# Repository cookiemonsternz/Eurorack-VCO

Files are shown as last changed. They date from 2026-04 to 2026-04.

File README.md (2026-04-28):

# VCO
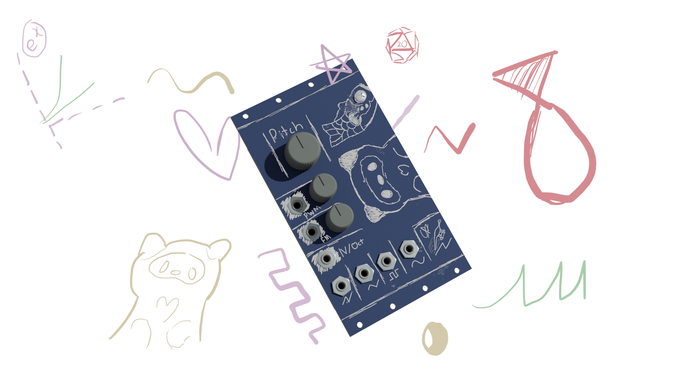
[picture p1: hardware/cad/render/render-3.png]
Render 3

_DIY VCO Eurorack module with saw, triangle, square, and sine output._

#### What?
This is a minimal, hand soldered, sawtooth core VCO module I designed to be inexpensive, fully analog, and with a variety of outputs. To that end, the module features sawtooth, triangle, pwm, and sine outputs, with pwm, fm, and pitch inputs. It internally features temparature tolerant circuitry, as well as having coarse and fine tuning, as well as pitch scale.

#### Why?
DIY eurorack modules are not particularly uncommon, but they often come at the cost of features. A lot of the time such modules lack functionality common to other prebuilt designs, and I wanted to change this. This module has a full standard feature set, including proper PWM and sine outputs.

Also, a lot of eurorack modules are quite bland in terms of design, often lacking any personality and focusing purely on cramming as many knobs in as possible. Here I've taken time to add some (imo) nice art and some extra space on the module.

#### How to use?
This should be pretty self explanatory:
- The pitch knob controls the pitch of the module. If using CV pitch, be sure to set this to the minimum.
- PWM input adjusts the width of the PWM output. The knob to the right of it controls the scale of the PWM CV.
- FM input modulates the frequency by the CV input. The knob controls the FM scale.
- Outputs are along the bottom!
Sawtooth, Triangle, PWM, and Sine, in that order.

#### Tuning
Hopefully, once you've received your pcb and soldered it up, it should look something like this:
Board back

Before you properly use it, you'll likely want to tune it.
This can be done by following these instructions:

1. Turn the `pitch` knob on the front of the board to the minimum.
2. Adjust the `coarse` trimpot on the back until the output is roughly A0 (~27.5Hz)
3. Adjust the `fine` trimpot to accurately tune the output.
4. Send 5V into the `1V/OCT` input on the front of the board.
5. Adjust the `scale` trimpot until your output is roughly A4 (~440Hz)
6. Repeat steps 2-5 several times until tuning is accurate at both A0 and A4.

Should the PWM output sound weird, just muck around with the `pwm` trimpot until it sounds normal.
Same thing with the sine or triangle output, just adjust the `tri off` trimpot.

#### Simulations
I've included the simulations I created on LTSpice; VCO contains the full circuit, PWM just the pwm section.

## Renders
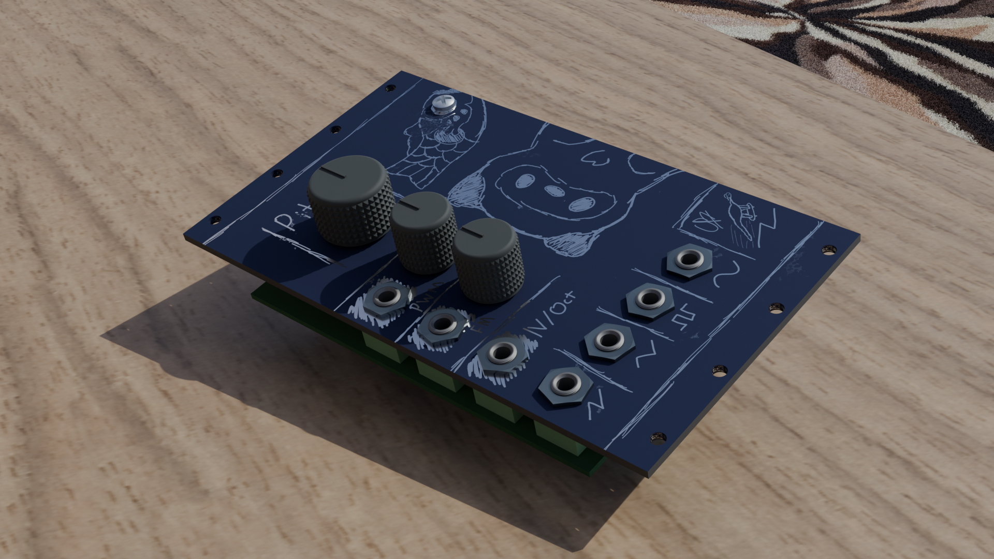
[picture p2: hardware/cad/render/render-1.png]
Render 1

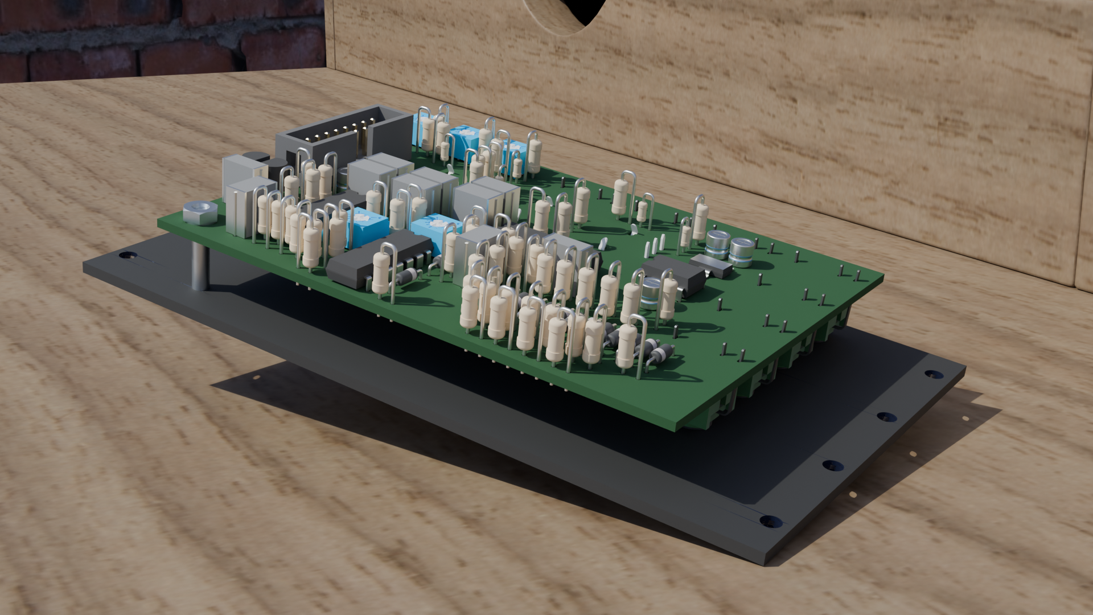
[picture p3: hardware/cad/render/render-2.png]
Render 2

Board Front
Board Back

## Zine Page

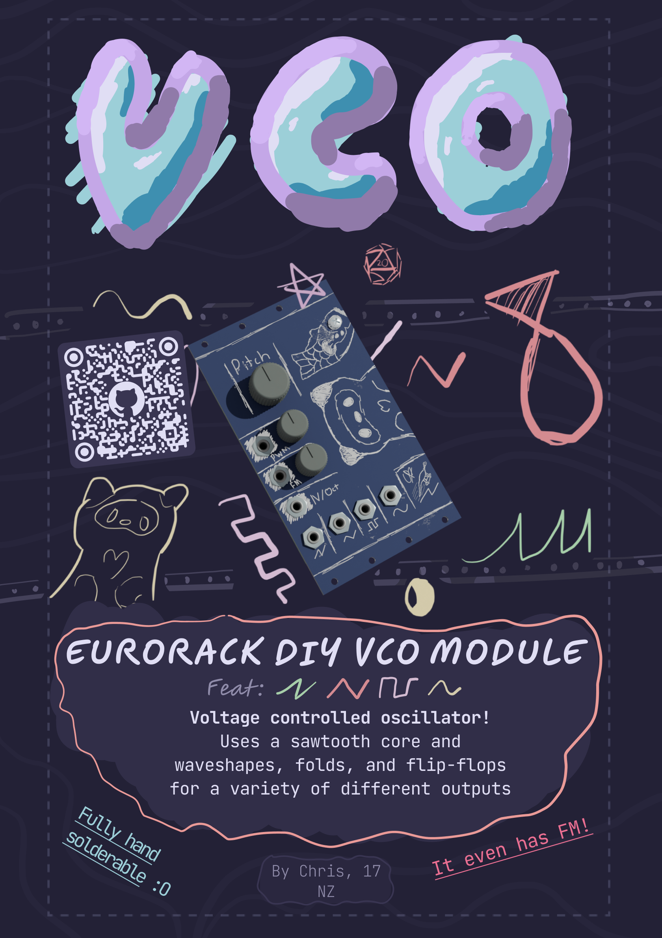
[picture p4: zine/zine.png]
Zine page


## BOM
_Needed is how many I personally need :)_
| Part | Quantity | Needed | Source | Link | Lot / Min Amount | Unit  | Net | Running | Total Incl. Unneeded |
|---|---|---|---|---|---|---|---|---|---|
| 10n Capacitor | 2 | 0 | LCSC | https://www.lcsc.com/product-detail/C20415578.html | 10 | $0.59 | NA | $0.00 | $0.59 |
| 100n Capacitor | 7 | 0 | LCSC | https://www.lcsc.com/product-detail/C49002969.html | 10 | $0.41 | NA | $0.00 | $1.00 |
| 10u Capacitor | 4 | 0 | LCSC | https://www.lcsc.com/product-detail/C49002971.html | 5 | $0.81 | NA | $0.00 | $1.81 |
| 22u Capacitor | 1 | 0 | LCSC | https://www.lcsc.com/product-detail/C18214342.html | 20 | $0.85 | NA | $0.00 | $2.66 |
| 100k Resistor | 15 | 0 | LCSC | https://www.lcsc.com/product-detail/C2843019.html | 100 | $0.82 | NA | $0.00 | $3.48 |
| 10k Resistor | 7 | 0 | LCSC | https://www.lcsc.com/product-detail/C2903232.html | 100 | $0.68 | NA | $0.00 | $4.16 |
| 1k Resistor | 6 | 0 | LCSC | https://www.lcsc.com/product-detail/C2903245.html | 100 | $0.68 | NA | $0.00 | $4.84 |
| 1M Resistor | 2 | 0 | LCSC | https://www.lcsc.com/product-detail/C2903250.html | 100 | $0.79 | NA | $0.00 | $5.63 |
| 47k Resistor | 3 | 0 | LCSC | https://www.lcsc.com/product-detail/C1364438.html | 100 | $0.52 | NA | $0.00 | $6.15 |
| 68k Resistor | 1 | 0 | LCSC | https://www.lcsc.com/product-detail/C1364508.html | 100 | $0.55 | NA | $0.00 | $6.70 |
| 14k Resistor | 1 | 0 | LCSC | https://www.lcsc.com/product-detail/C1369251.html | 100 | $0.87 | NA | $0.00 | $7.57 |
| 20k Resistor | 1 | 0 | LCSC | https://www.lcsc.com/product-detail/C119353.html | 50 | $0.57 | NA | $0.00 | $8.14 |
| 200r Resistor | 1 | 0 | LCSC | https://www.lcsc.com/product-detail/C714576.html | 20 | $0.68 | NA | $0.00 | $8.82 |
| 2k Resistor | 1 | 0 | LCSC | https://www.lcsc.com/product-detail/C119330.html | 50 | $0.52 | NA | $0.00 | $9.34 |
| 100r Resistor | 2 | 0 | LCSC | https://www.lcsc.com/product-detail/C1366145.html | 10 | $0.57 | NA | $0.00 | $9.91 |
| 33r Resistor | 2 | 0 | LCSC | https://www.lcsc.com/product-detail/C713968.html | 100 | $0.70 | NA | $0.00 | $10.61 |
| 82r Resistor | 2 | 0 | LCSC | https://www.lcsc.com/product-detail/C119302.html | 50 | $0.50 | NA | $0.00 | $11.11 |
| 470r Resistor | 1 | 0 | LCSC | https://www.lcsc.com/product-detail/C129899.html | 50 | $0.54 | NA | $0.00 | $11.65 |
| 47r Resistor | 2 | 0 | LCSC | https://www.lcsc.com/product-detail/C119296.html | 50 | $0.57 | NA | $0.00 | $12.22 |
| 330r Resistor | 1 | 0 | LCSC | https://www.lcsc.com/product-detail/C713986.html | 100 | $0.75 | NA | $0.00 | $12.97 |
| 30r Resistor | 2 | 0 | LCSC | https://www.lcsc.com/product-detail/C18724276.html | 50 | $0.51 | NA | $0.00 | $13.48 |
| 120r Resistor | 1 | 0 | LCSC | https://www.lcsc.com/product-detail/C173141.html | 50 | $1.10 | NA | $0.00 | $14.58 |
| 39r Resistor | 2 | 0 | LCSC | https://www.lcsc.com/product-detail/C119294.html | 50 | $0.53 | NA | $0.00 | $15.11 |
| 6.8k Resistor | 1 | 0 | LCSC | https://www.lcsc.com/product-detail/C3397534.html | 50 | $0.80 | NA | $0.00 | $15.91 |
| BC557B | 1 | 0 | LCSC | https://www.lcsc.com/product-detail/C512874.html | 5 | $0.43 | NA | $0.00 | $16.34 |
| BC547B | 1 | 0 | LCSC | https://www.lcsc.com/product-detail/C900798.html | 5 | $0.42 | NA | $0.00 | $16.76 |
| Diode (1N4148) | 15 | 15 | LCSC | https://www.lcsc.com/product-detail/C402212.html | 50 | $0.47 | $0.47 | $0.47 | $17.23 |
| 3362P 1k Trimpot | 1 | 1 | LCSC | https://www.lcsc.com/product-detail/C118947.html | 5 | $0.72 | $0.72 | $1.19 | $17.95 |
| 3362P 10k Trimpot | 1 | 1 | LCSC | https://www.lcsc.com/product-detail/C118956.html | 5 | $0.82 | $0.82 | $2.01 | $18.77 |
| 3362P 100k Trimpot | 3 | 3 | LCSC | https://www.lcsc.com/product-detail/C118966.html | 5 | $0.77 | $0.77 | $2.78 | $19.54 |
| RK097 1M Vertical Pot | 1 | 0 | Aliexpress | https://www.aliexpress.com/item/1005007278123055.html | 5 | $1.83 | NA | $2.78 | $21.37 |
| RK097 100k Vertical Pot | 2 | 0 | Aliexpress | https://www.aliexpress.com/item/1005007278123055.html | 5 | $1.83 | NA | $2.78 | $23.20 |
| 10k NTC Thermistor | 5 | 5 | LCSC | https://www.lcsc.com/product-detail/C13879.html | 10 | $0.44 | $0.44 | $3.22 | $23.64 |
| TL074 | 3 | 3 | LCSC | https://www.lcsc.com/product-detail/C133542.html | 1 | $0.69 | $2.08 | $5.30 | $24.33 |
| AMS1117-2.5 SOT223 | 1 | 1 | LCSC | https://www.lcsc.com/product-detail/C12087.html | 5 | $0.26 | $1.29 | $6.59 | $24.59 |
| TC7660 | 1 | 1 | LCSC | https://www.lcsc.com/product-detail/C640848.html | 1 | $1.90 | $1.90 | $8.49 | $26.49 |
| PJ301F Audio Jack | 7 | 7 | Aliexpress | https://www.aliexpress.com/item/1005007344185064.html | 10 | $3.66 | $3.66 | $12.15  | $30.15 |
| 2x8 2.54mm IDC | 1 | 1 | LCSC | https://www.lcsc.com/product-detail/C7430313.html | 5 | $0.08 | $0.42 | $12.57  | $30.23 |
| Aluminium Plate (100x200x2mm) | 1 | 1 | Aliexpress | www.aliexpress.com/item/1005007160296738.html | 1 | $6.23 | $6.23 | $18.80  | $36.46 |
| M3x18mm Bolt | 1 | 0 | Aliexpress | https://www.aliexpress.com/item/32810852732.html | 50 | $6.43 | NA | $18.80  | $42.89 |
| M3 Hex Nut | 1 | 0 | Aliexpress | https://www.aliexpress.com/item/1005007593861199.html | 50 | $4.89 | NA | $18.80  | $47.78 |

| Totals | Cost |
|---|---|
| Aliexpress, Inc. Shipping + Tax | $12.67 |
| LCSC, Inc. Shipping + Tax | $11.83 |
| Totals | $24.50 |

## CAD Links
Heres the links to the CAD source, Onshape:
[Panel source](https://cad.onshape.com/documents/2eb193865095ed64e7d8f18f/w/39a8bf3aab3e330703d68c10/e/c0b4bed9abee9891cf892ccc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)

## Directory Structure
- **hardware/**
    - **bom/** - BOM Files (CSV and LibreOffice Calc)
    - **cad/** - CAD Files
        - **render/** - Files for rendering (inc. gltf models)
    - **ltspice/** - LTSpice electrical simulations
    - **vco/** - KiCad files
        - **lib/** - External libraries
        - **production/** - Production files (Gerber, etc.)
- **journals/**
- **zine/** - Zine page :)

## References
Circuit design influenced by:
[Moritz Klein DIY VCO Series](https://www.youtube.com/playlist?list=PLHeL0JWdJLvTuGCyC3qvx0RM39YvopVQN)
[Falstad Diode Clipper](https://www.falstad.com/circuit/e-diodeclip.html)

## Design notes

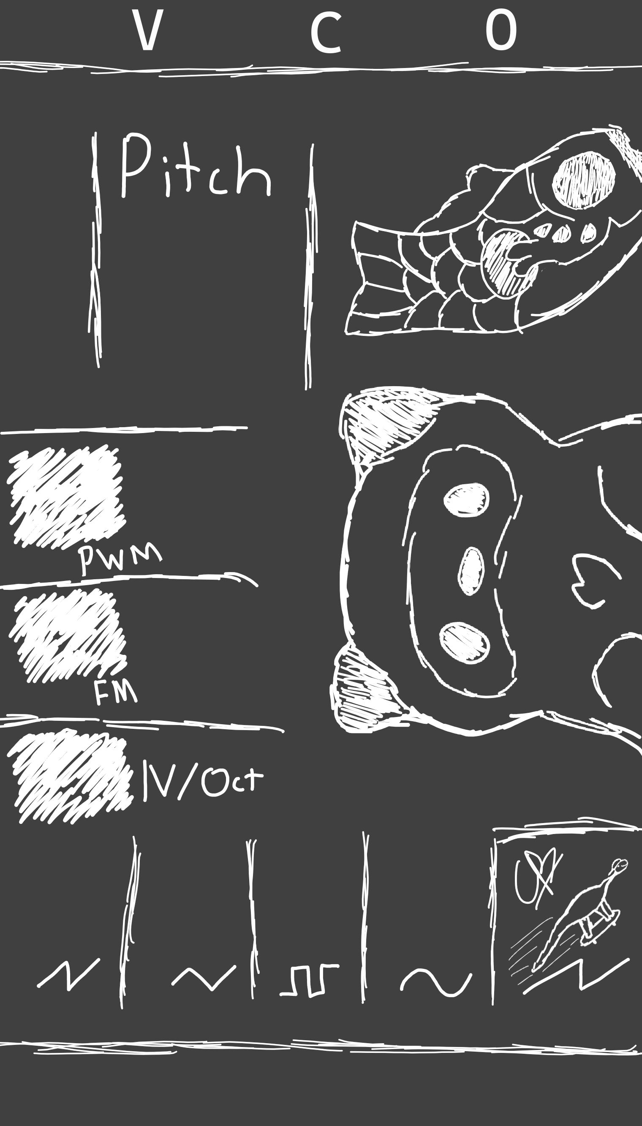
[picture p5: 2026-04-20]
hardware/cad/panel-art.png

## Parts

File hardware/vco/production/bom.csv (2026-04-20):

Designator | Footprint | Quantity | Value | LCSC Part #
C1, C3 | C_Rect_L9.0mm_W3.3mm_P7.50mm_MKT | 2 | 10n
C10, C2, C4, C5, C6, C7, C8, C9 | C_Rect_L9.0mm_W4.2mm_P7.50mm_MKT | 8 | 100n
C11, C12, C13, C15 | CP_Radial_D4.0mm_P2.00mm | 4 | 10u
C14 | CP_Radial_D4.0mm_P2.00mm | 1 | 22u
D1, D10, D11, D12, D13, D14, D15, D2, D3, D4, D5, D6, D7, D8, D9 | D_DO-35_SOD27_P7.62mm_Horizontal | 15 | 1N4148
J1, J2, J3, J4, J5, J6, J7 | Jack_3.5mm_QingPu_WQP-PJ301M-12_Vertical | 7 | AudioJack2
J8 | IDC-Header_2x08_P2.54mm_Vertical | 1 | 16 Pin IDC
Q1 | TO-92_Inline | 1 | BC557B
Q2 | TO-92_Inline | 1 | BC547B
R1, R13, R19, R2, R20, R21, R23, R29, R3, R5, R54, R55, R56, R7, R8 | R_Axial_DIN0207_L6.3mm_D2.5mm_P2.54mm_Vertical | 15 | 100k
R10, R11, R12 | R_Axial_DIN0207_L6.3mm_D2.5mm_P2.54mm_Vertical | 3 | 47k
R14, R15, R17, R18, R26, R30, R31, R52 | R_Axial_DIN0207_L6.3mm_D2.5mm_P2.54mm_Vertical | 8 | 10k
R16, R22, R27, R32, R39, R4, R53 | R_Axial_DIN0207_L6.3mm_D2.5mm_P2.54mm_Vertical | 7 | 1k
R24 | R_Axial_DIN0207_L6.3mm_D2.5mm_P2.54mm_Vertical | 1 | 68k
R25 | R_Axial_DIN0207_L6.3mm_D2.5mm_P2.54mm_Vertical | 1 | 14k
R28 | R_Axial_DIN0207_L6.3mm_D2.5mm_P2.54mm_Vertical | 1 | 20k
R33 | R_Axial_DIN0207_L6.3mm_D2.5mm_P2.54mm_Vertical | 1 | 200
R34 | R_Axial_DIN0207_L6.3mm_D2.5mm_P2.54mm_Vertical | 1 | 2k
R35, R36 | R_Axial_DIN0207_L6.3mm_D2.5mm_P2.54mm_Vertical | 2 | 100
R37, R38 | R_Axial_DIN0207_L6.3mm_D2.5mm_P2.54mm_Vertical | 2 | 33
R40, R41 | R_Axial_DIN0207_L6.3mm_D2.5mm_P2.54mm_Vertical | 2 | 82
R42 | R_Axial_DIN0207_L6.3mm_D2.5mm_P2.54mm_Vertical | 1 | 470
R43, R44 | R_Axial_DIN0207_L6.3mm_D2.5mm_P2.54mm_Vertical | 2 | 47
R45 | R_Axial_DIN0207_L6.3mm_D2.5mm_P2.54mm_Vertical | 1 | 330
R46, R47 | R_Axial_DIN0207_L6.3mm_D2.5mm_P2.54mm_Vertical | 2 | 30
R48 | R_Axial_DIN0207_L6.3mm_D2.5mm_P2.54mm_Vertical | 1 | 120
R49, R50 | R_Axial_DIN0207_L6.3mm_D2.5mm_P2.54mm_Vertical | 2 | 39
R51 | R_Axial_DIN0207_L6.3mm_D2.5mm_P2.54mm_Vertical | 1 | 6.8k
R6, R9 | R_Axial_DIN0207_L6.3mm_D2.5mm_P2.54mm_Vertical | 2 | 1M
RV1, RV2, RV5 | TRIM_3362P-1-253LF | 3 | 100k
RV3 | Potentiometer_Alps_RK09L_Single_Vertical | 1 | 1M
RV4 | TRIM_3362P-1-253LF | 1 | 1k
RV6 | Potentiometer_Alps_RK09L_Single_Vertical | 1 | 250k
RV7 | TRIM_3362P-1-253LF | 1 | 10k
RV8 | Potentiometer_Alps_RK09L_Single_Vertical | 1 | 100k
TH1, TH2, TH3, TH4, TH5 | R_Axial_DIN0204_L3.6mm_D1.6mm_P1.90mm_Vertical | 5 | 10k NTC
U1, U2, U3 | DIP-14_W7.62mm | 3 | TL074
U4 | SOT-223-3_TabPin2 | 1 | AMS1117-2.5
U5 | DIL08 | 1 | TC7660

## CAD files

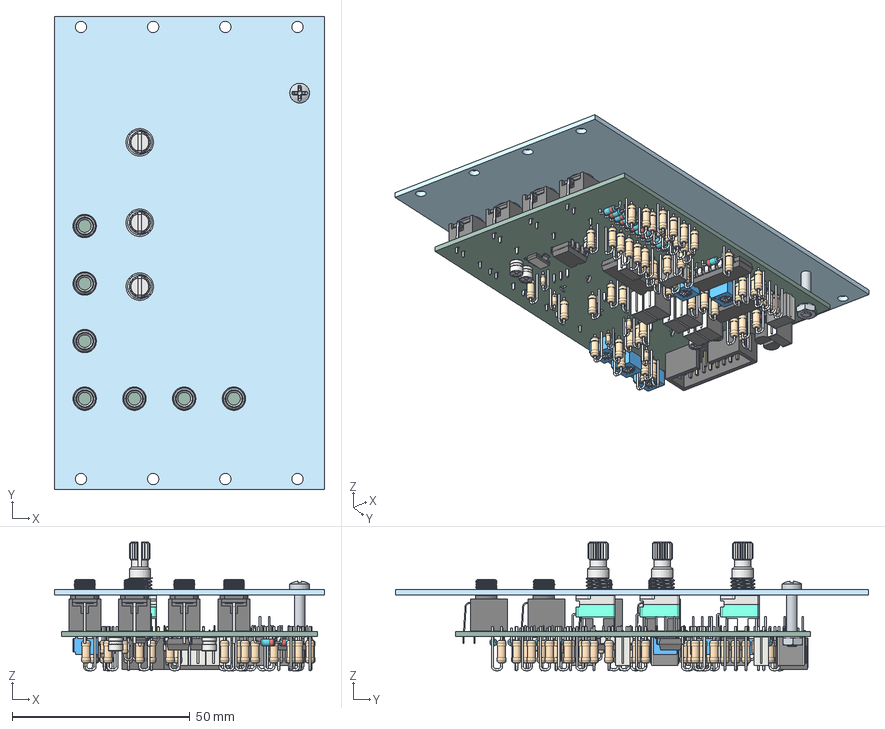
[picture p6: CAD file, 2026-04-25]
hardware/cad/assembly.step
76.0 x 133.2 x 36.2 mm
PH Pan head screw M3x0.50 x 16
Hex nut style 1 grade A & B M3x0.5
3362P-1-253LF x 25
R_Axial_DIN0207_L6.3mm_D2.5mm_P2.54mm_Vertical x 56
Vertical Potentiometer 15mm Axis x 18
DIP-14_W7.62mm x 3
C_Rect_L9.0mm_W4.2mm_P7.50mm_MKT x 8
CP_Radial_D4.0mm_P2.00mm x 5
D_DO-35_SOD27_P7.62mm_Horizontal x 30
TO-92_Inline x 2
vco_PCB
SOT-223
DIP-8_W7.62mm
R_Axial_DIN0204_L3.6mm_D1.6mm_P1.90mm_Vertical x 5
IDC-Header_2x08_P2.54mm_Vertical
C_Rect_L9.0mm_W3.3mm_P7.50mm_MKT x 2

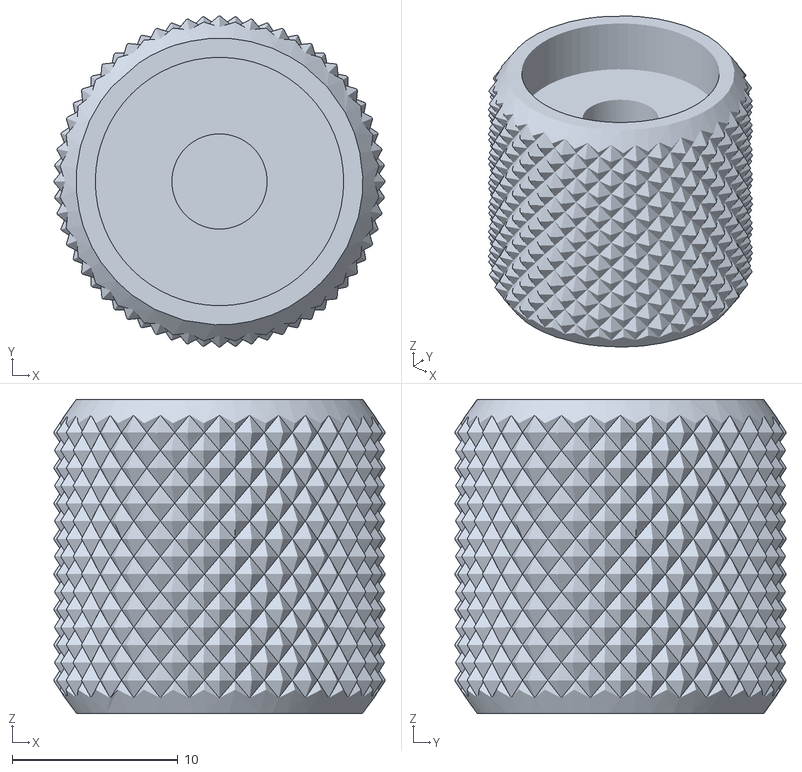
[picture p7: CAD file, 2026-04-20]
hardware/cad/render/LittleKnob.stl
20.0 x 20.0 x 19.0

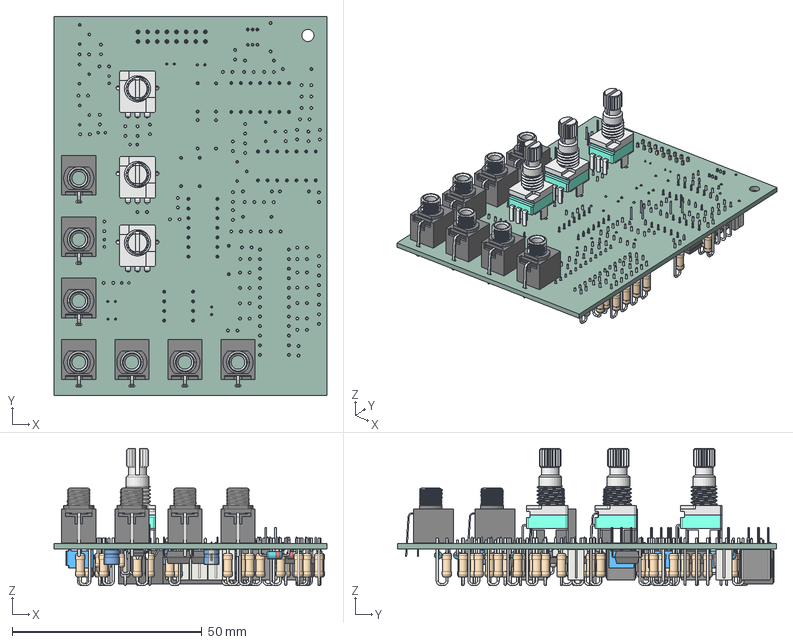
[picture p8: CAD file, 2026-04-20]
hardware/cad/board.step
72.0 x 100.0 x 36.2 mm
Vertical Potentiometer 15mm Axis x 3
3362P-1-253LF x 5
R_Axial_DIN0207_L6.3mm_D2.5mm_P2.54mm_Vertical x 56
CP_Radial_D4.0mm_P2.00mm x 5
C_Rect_L9.0mm_W4.2mm_P7.50mm_MKT x 8
DIP-8_W7.62mm
R_Axial_DIN0204_L3.6mm_D1.6mm_P1.90mm_Vertical x 5
D_DO-35_SOD27_P7.62mm_Horizontal x 15
C_Rect_L9.0mm_W3.3mm_P7.50mm_MKT x 2
DIP-14_W7.62mm x 3
TO-92_Inline x 2
SOT-223
IDC-Header_2x08_P2.54mm_Vertical
vco_PCB

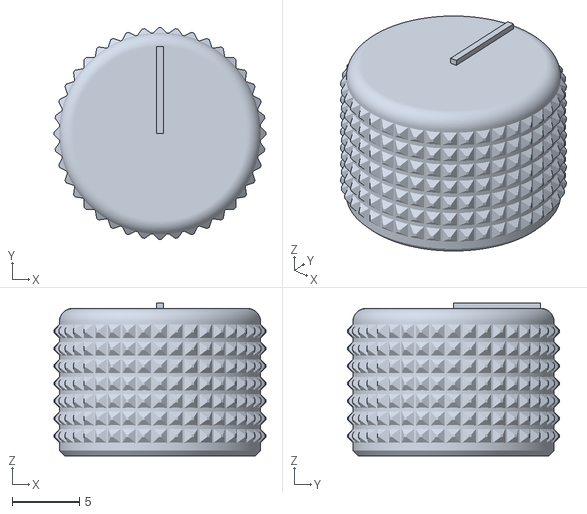
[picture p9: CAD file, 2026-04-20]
hardware/cad/render/BigKnob.stl
15.8 x 15.8 x 11.4

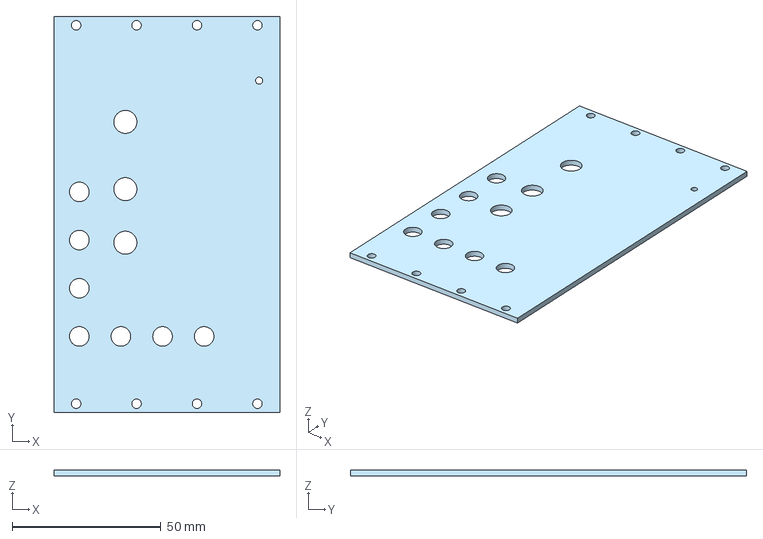
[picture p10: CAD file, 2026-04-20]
hardware/cad/panel.step
76.0 x 133.2 x 2.00 mm

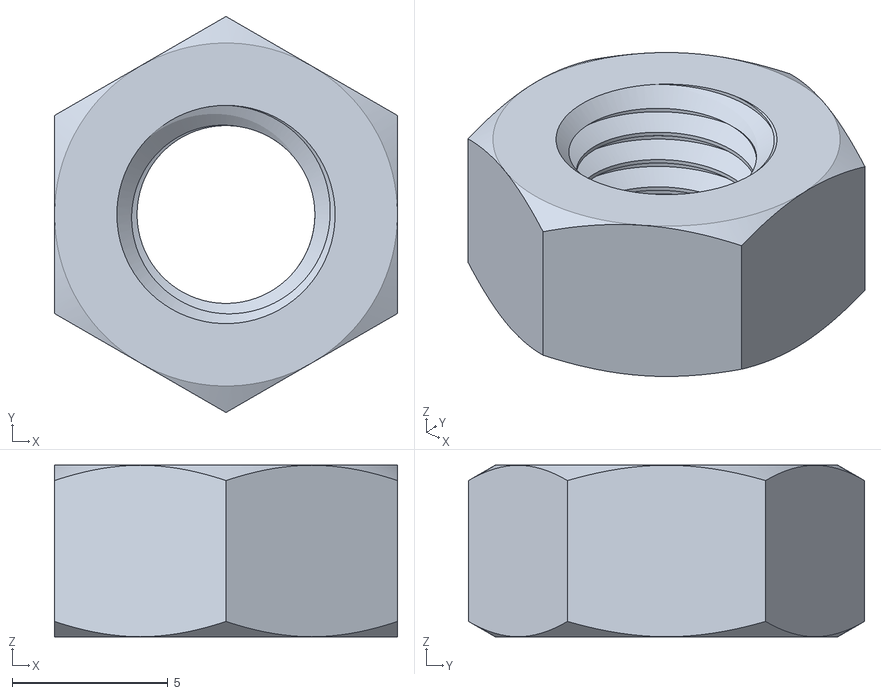
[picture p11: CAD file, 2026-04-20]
hardware/cad/render/M7 Nut.stl
11.0 x 12.7 x 5.50

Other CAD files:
hardware/cad/panel.dxf
hardware/cad/render/assets/models/carpet_fd1ce773-036e-483d-939a-88eaa8cc369d/carpet_1K_8ea8a808-048c-4424-911d-2f735cfe2d15.blend
hardware/cad/render/assets/models/decor-corner-tab_f83bcaf6-eb8e-4abc-be47-4dfca3b4c605/decor-corner-table_1K_0db104de-feeb-4c32-83cc-51334298a932.blend
hardware/cad/render/assets/models/scan-brick-wall-_99df1fa8-1cf8-4d82-aba5-198fff7a844b/scan-brick-wall-red_2K_be58a61b-e343-4ed9-9f83-84594f3e12b2.blend

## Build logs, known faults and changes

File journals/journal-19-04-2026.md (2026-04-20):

# Journal 5 - 19/04/2026

I'm back! My goal of getting sleep was largely unsuccessful because I stayed up till quite late playing bg3, but I am back now and ready to rock and roll!

I'll crack straight into pcb work :)

And yeah everything is fitting rather nicely now:
Layout take two

I'll just quickly route it.

annnnd I just realized I forgot my voltage regulators :(
LDO + Charge pump

I decided to go with an LDO and then a charge pump because it's quite hard to find negative ldo's.

And now its fully routed :)
Routed

I'll do some drc and clean up the silkscreen and then work on the smd version mayhaps
And now drc is happy, haven't done silkscreen yet though. 
DRC'd

And theres the silkscreen stuff done:
Silkscreen done

---

Now that's done, I'll work on the bom for the tht version.
I do already have a bunch of capacitors and resistors, so I won't be buying them but I'll include them in the BOM irregardless.

---

Well I finished the bom but my computer shutdown and I didn't save so I guess I'm doing it again.

Ok done:
BOM

I haven't put in the resistors and capacitors yet, but thats the estimate total for parts.

Most of these are choice, so free shipping, but theres a few which aren't so I'll slap on an extra 8 bucks for that, plus the board and shipping, and it's looking like a total of around $35.

That seems like a pretty reasonable amount to me, and it also fits nicely within the project budget.

---

Next up, some CAD work :)
I'll first get some 3d models for the parts missing them in kicad, and that should help with the design.

And heres the full 3D pcb:
Back of pcb 3d
Front of pcb 3d

I theoretically don't need any mounting hardware on the pcb, as it should be all held in by the knobs and inputs/outputs but I think I will include one screw in the top right, as otherwise it'll be a bit flimsy there I reckon.

Annnd heres the front panel :)
Front Panel

What I'll do is just buy a roughly right sized piece of aluminum, cut it down to size and then drill some holes. Only hard part will be cutting it down to size, I know my drill can get through much thicker metal than this (2mm al).

Panel 3d View

Panel Back 3d view

I've ended up with a depth of ~20mm, which is very good. Should fit in pretty much every case which is nice :)

And that just about wraps up the project! Wow thats cool :)

I'll make a quick list of whats left to do now:
- Readme
- Renders
- Update bom with actual costs (inc. shipping and panel)
- Art for panel front
- Production exports
- Include resistors and capacitors on BOM

## Prod Exports
Very easy using the kicad jlcpcb tool script thingy :)

## Panel front art

I've decided to go with reverse etching, so I have one solid colour on the panel which is then etched away in a pattern. Good thing about this is that I can also change my mind later, as the pattern just needs to be a basic mask which is the same as whats needed for lots of other techniques. 

Enough yap now, I need to decide what I'm actually going to put on it :O

---

ps reviewer fire alarm went off so theres a bit of a gap (no fire dw)

---

Man I'm slow at art :(
Anyways, I think I've got it done now, here's what I settled on:
Panel Art
soup themed + my rad dino

## Renders

I've imported everything into blender, and now just need to sort materials.

--- 

Welp now they're sorted, just need to wait for rendering :)
Might do a couple angles as well + an exploded view in a more stylized way for the magazine page.

Render 1
Render 2

---

Magazine one:
Render Magazine

And thats where I'll leave it for today. Tomorrow I'll get the final stuff sorted out, like a readme, fixing the bom, a proper zine page, and then submission.

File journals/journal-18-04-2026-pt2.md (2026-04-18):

# Journal 4 - 18/04/2026 - PART 2

Hello again! I have quickly transferred it into KiCad and it's looking decent! 
KiCad Schematic

Not done yet (still have to wire up connectors and power) but it's pretty close.

---

Speaking of, I've finished this off and now we've got all of the jacks:
Jacks and connectors

---

Now that the schematic is done, I've got a choice to make; Am I gonna get it assembled, or do it myself?
What I reckon I'll do is make two versions, one with all tht components and one designed for pcba. I'll look at the costs and see which ones cheaper / feasible to fit on a board.

---

Alrighty, trying to sort a footprint for audio jacks, but KiCad is being annoying so I'm going to switch to windows.

---

And here's the tht version with all components! I tried to use common things, but also things that were available on jlc for the smd version should I go with that.
THT version

I'd like to have a roughly 12HP module? It's the same as Plaits (very popular vco). I'm not too worried about size, under 15-20HP would be preferable, but if I can get it in 12 that would be sick.

Eurorack uses 3U height, which is 133.35mm. In order to fit between the rails however, the pcb must have a max height of 108-110mm. I've opted for 100mm because jlc pricing :) (over 100mm in any dimension is an extra $6).

For with, each HP is 5.08mm, so 12 is 60.96mm. Going with a 55mm width leaves ~3mm of clearance on each side which I'm happy with.
Heres what it looks like for reference.

Board size

Could be a bit of a squeeze but I reckon I can make it work.

---

You know what I'm completely missing? An actual pitch knob :O
I've got the tune one but thats probably not good to adjust all the time bc then you lose your tuning.
I'll quickly add a proper knob in.

Welp those changes were made and I've started laying out the pcb.
I've managed to fit most of it in, except there is no chance that the sine wave section will fit.
Half routed tht

I also would like a bit more space for routing, as I'm aiming for just a 2 layer board.
I'll try a 15HP board and see how that changes stuff.

I do however want to do some baldurs gate first, and schools nearly starting up again so I need a somewhat decent sleep schedule, so trying that's gonna have to wait till tomorrow :)

Sooooo gn :O

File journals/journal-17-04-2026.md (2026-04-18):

# VCO Journal 2 - 17/04/2026

Hello again! My internet was out for the earlier morning, but I've been doing some work on this offline and it's going super well :) I replaced the CV scaling and offset section to make it more usable IRL, with potentiometers instead of static resistors, and also added thermistors because some person on the internet said to \:)

A great side effect of this is it's actually working properly now; I've tuned it to A1 and after adjusting some timestep settings in LTSpice, it can happily go all the way up to 15kHz, equivalent of A9 which is a simply gargantuan range. If needed, it can also go lower, down to around 15Hz at the moment but by tweaking some resistor values I'm sure I could get it lower and make it into a proper LFO if needed.

Heres the new input section as of now:
New section

At super low frequencies the triangle and sine wave get a bit distorted, but as soon as you're above ~100Hz it's fine, so I'm not particularly worried about that.

I have now met all of my compulsory design requirements, but its only been a couple days on this project total, and I feel like the pwm output is calling to me. 

I'm going to try and design a little pwm circuit with no references, and see how it turns out; potentially a bad idea but whatever it'll be fun :)

---

And here's what I've come up with:
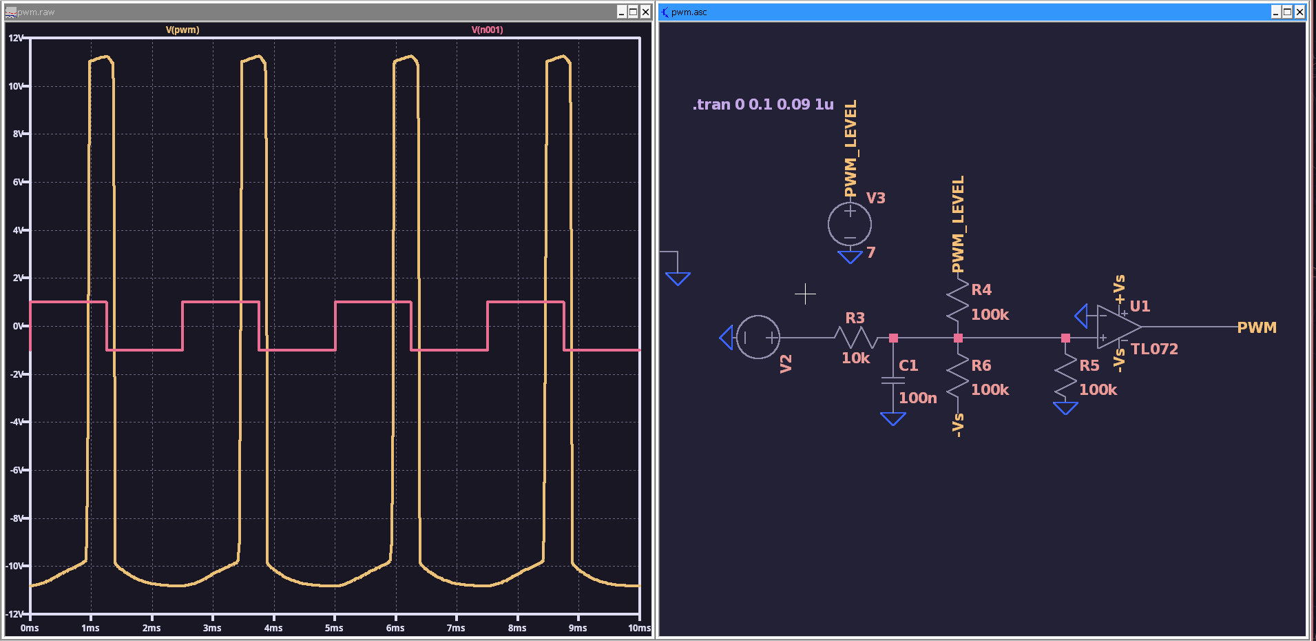
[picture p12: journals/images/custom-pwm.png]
My pwm circuit

It does work rather well, with the pwm level going from -6v to +6v (which could be scaled and offset easily) but there is a problem in that it only works at one frequency. This is because I used an RC filter to turn it into a sort of triangle wave, which changes amplitude at different frequencies.

<s>I'll have a look at how some actual smart people did it and see whats different.</s>
Nevermind I just realized that I can just use my triangle wave input lol.

Heres my final design, it works regardless of frequency, and has a CV input range of -5 to +5v, which is typical for eurorack. It does assume that the triangle is 10v p2p around gnd, which is also typical for eurorack and I can ensure this myself.
My pwm circuit v2

And integrating it into my actual design:
Full circuit

I also went through and made sure most of the outputs were scaled correctly, so all of them are ~10v p2p, and kinda half centered around ground.

It's not perfect but all modules have input decoupling anyways, so it shouldn't be a massive problem.

With that, I'm going to say this VCO design is done :)

Tomorrow, I'll start working on transferring it to kicad and getting the pcb sorted, but for now I've got a gig I need to get ready for; Tchuss!

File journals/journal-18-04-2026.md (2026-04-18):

# VCO Journal 3 - 18/04/2026

Hello again!

I lied yesterday a bit, I've got a few more changes I'd like to make to the circuit that I've been thinking about overnight. Namely...
- Clean it up a bit (get rid of redundant buffering / sections)
- Move the pwm generation from the triangle wave to the sawtooth wave (triangle is messy)
- Try and fix the triangle wave
- Get rid of sawtooth offset

---

First of all, I figured out that the output high pass filter for my sawtooth wave was set to 0.15Hz, which is quite low, so increasing this to ~15-20Hz should help remove any dc offset.

And yep now its a very nice -6V to 6V
Sawtooth w/o dc offset

---

### Triangle stuff!

I made a couple tweaks from some comments I found online, and adding a small capacitor over the feedback resistor and adding a trimpot in series very much helps (trimpot will only matter irl so not included here).

Better triangle
Much much much cleaner, also the tidy up I did to the sawtooth meant that I could get rid of the bias tweaking and just chuck it straight to ground.

Also changed around the filtering and scaling and now it's a pretty clean 10v p2p at gnd (not in the screenshot though cos I hadn't done that yet).

---

### PWM on sawtooth + tidy up.

I've not only swapped it over to run off the sawtooth, but also rejiggerated the cv processing a wee bit. It's now in the proper +-5V range, and theres a trimpot for adjustment (and also so that its just a square wave when the cv is disconnected).

PWM

---

### Cleaner triangle also means cleaner sine wave!
Now with proper output scaling and impedance :)
Sing

---

I've also decided to get rid of the flip flop square wave. It can just be emulated with the pwm output (albeit a tiny bit less cleanly) but the extra component cost (an uncommon-ish one as well) probably isn't worth it.

I've also went around and made sure all of the outputs have the correct impedance :)

And with that, the VCO design is officially complete!
VCO full

Pretty decent looking if I do say so myself. Some things are a bit wonky but who cares.

And at higher frequencies:
High freq

And lower frequencies:
Low freq

Not amazing amazing at low frequencies, but this is ~30Hz, which will not be often used, and it should also be able to be fixed by adjusting the trimpot in the triangle section. 

Overall, pretty happy with this and about ready to call it done :)
In fact, I'm going to start getting it into KiCad now :O
Might do it in a seperate journal later though, bc I want to appease soup (they need their koi).

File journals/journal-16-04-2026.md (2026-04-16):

# VCO Journal 1 - 16/04/2026

Hello people and welcome to yet another late night project beginning! I was just about to do some work on my BlokkFX project but I'm a bit burnt out atm with it from all the work I've been doing lol, so I've decided to start another thing :)

This is going to be the first in a series of projects where I make a bunch of mini little eurorack modules, and for this first one: A basic VCO.
Getting straight into it, here are my design requirements

### Design Requirements
- Audible range (~20Hz-20kHz)
- Sine, Sawtooth, and Square outputs (i hate triangle waves)
- 1V/oct freq control
- PWM out and ctrl if i feel like it

Seems pretty easy to me! Time to do some research on oscillators :) I did a bit of stuff with a synth I designed for blueprint, but that never really went anywhere and falstad kept screwing me over.

For the oscillator core, I'm going to go with the same as I did for my other synth, and use an integrator to generate a triangle wave. 

---

Alrighty, I've been having some trouble with LTSpice so I'm going to bring in my old synth design (which I know works) and build off of that...

And that's looking much much more stable than before, plus it's got the built in temperature independence from last time :)
VCO Initial

And quickly adding a square wave by using a flip flop on the pulse output:
Square output

And I'm pretty sure I can easily get a triangle by running the square through an integrator, and then from there just filter it into a sine wave.
Actually after some testing + research, I've realised that an integrator will only work properly at one specific frequency. Fortunately, there is an easier path to go down. Because I already have a sawtooth output I can do something with it, all I need to do is invert it and that's a trivial task

And with that, we now have triangle output as well :)
Triangle Output

And heres all of the waves at once
All at once

Not too shabby if I do say so myself. The final thing I need to add is a sine wave output, which should be easy enough.
I've come across a few ways to do this, either just a simple low pass filter, using diodes to sequentially clip the tops of the wave, or using a long tailed transistor pair structure somehow (I need to look into this one more.)

I tried filtering and it works well for one specific frequency but once you start changing it it gets quite gross looking. I'll go with the diode based one as I don't want to deal with transistor matching unless I have to (+ it adds more temperature concerns)

Diode ladder works very well, but it does need specific input range (~5V p2p) and also needs steady +-2.4V voltage references, but I think I might go with this as it's easy to sort out with just a few ldo chips.
Diode sine

Welp I almost got it done but its decided to randomly stop working :(
I'll troubleshoot this tomorrow I want to play some bg3 :)

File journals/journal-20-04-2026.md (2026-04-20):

# VCO Journal 6 - 20/04/2026

I've started work on the readme, will put something here when its done.

---
Things I've done as I worked on the readme:

- Optimise costs:
    - Bought some parts via LCSC instead of Ali
    - Brought total cost down from ~$35 to ~$25
- Update panel art
    - Added VCO text at top to differentiate it. 
- Fixed BOM
    - Added the parts I already have

--- 

Ok the readme is done!
readme

and that's pretty much my project finished! Went through the fallout submission requirements and it seems I meet everything really :)

---

I did up a wee zine page as well :O
Zine page

Also added the schematic plots

---

And with that, the project is complete!
I'm going to wrap up this journal and then submit! 

Adios amigos!

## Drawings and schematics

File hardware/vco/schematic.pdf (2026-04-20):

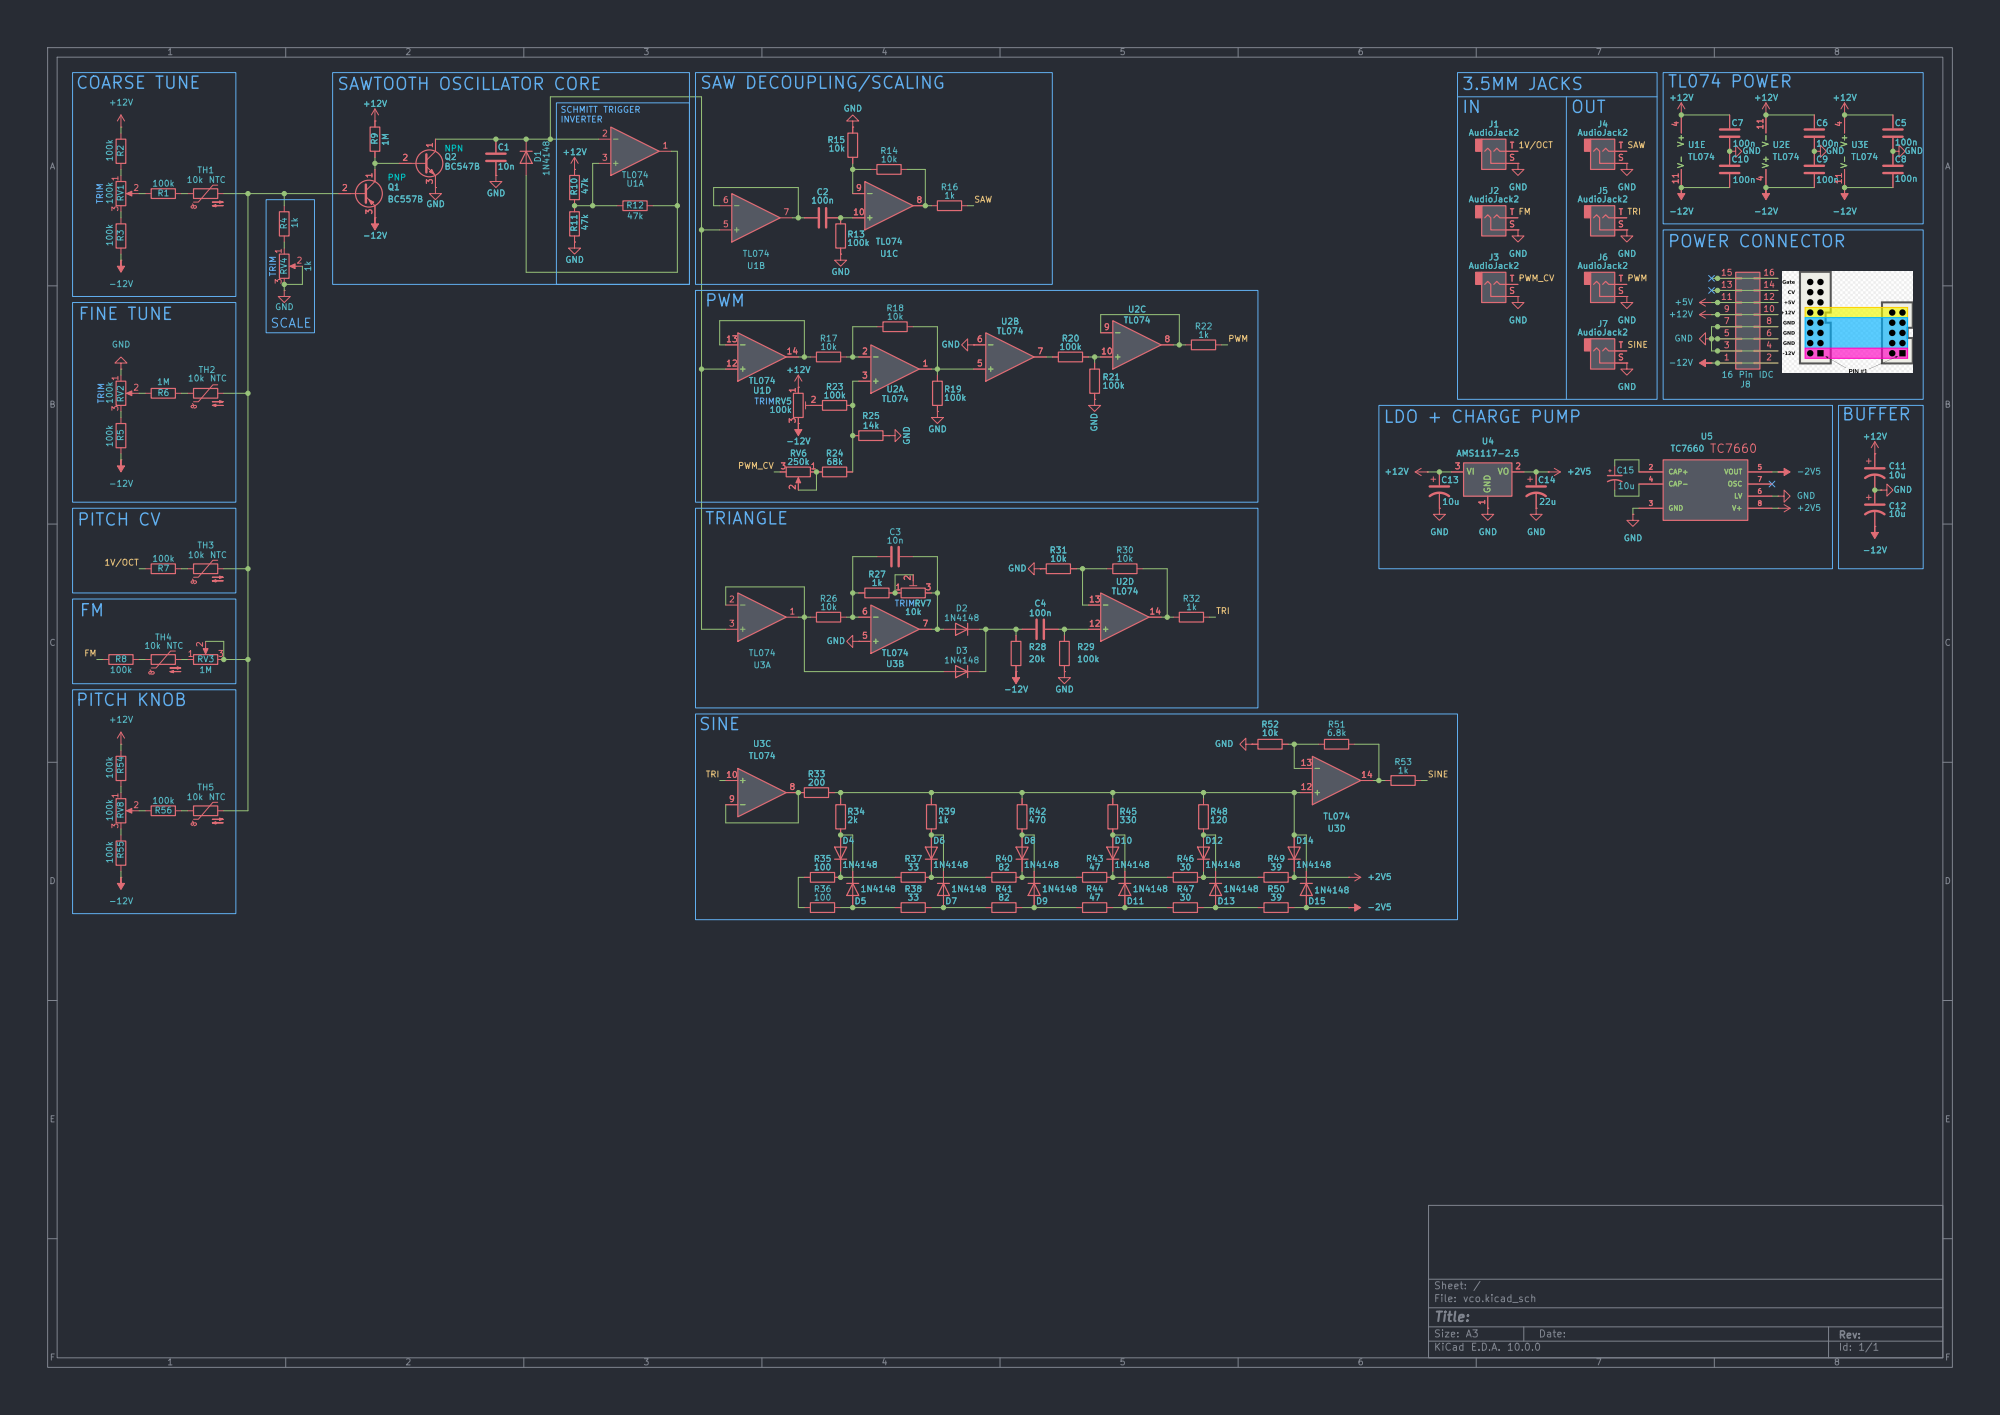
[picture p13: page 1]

J1 J1 AudioJack2 TGND GND GND GND | OUT J4 J4 AudioJack2 TGND GND GND GND GND

SCHMITT TRIGGER | 2 +

PNP FINE TUNE TRIM

Size: A3 | Rev: | F Date:
KiCad E.D.A. 10.0.0 | Id: 1/1

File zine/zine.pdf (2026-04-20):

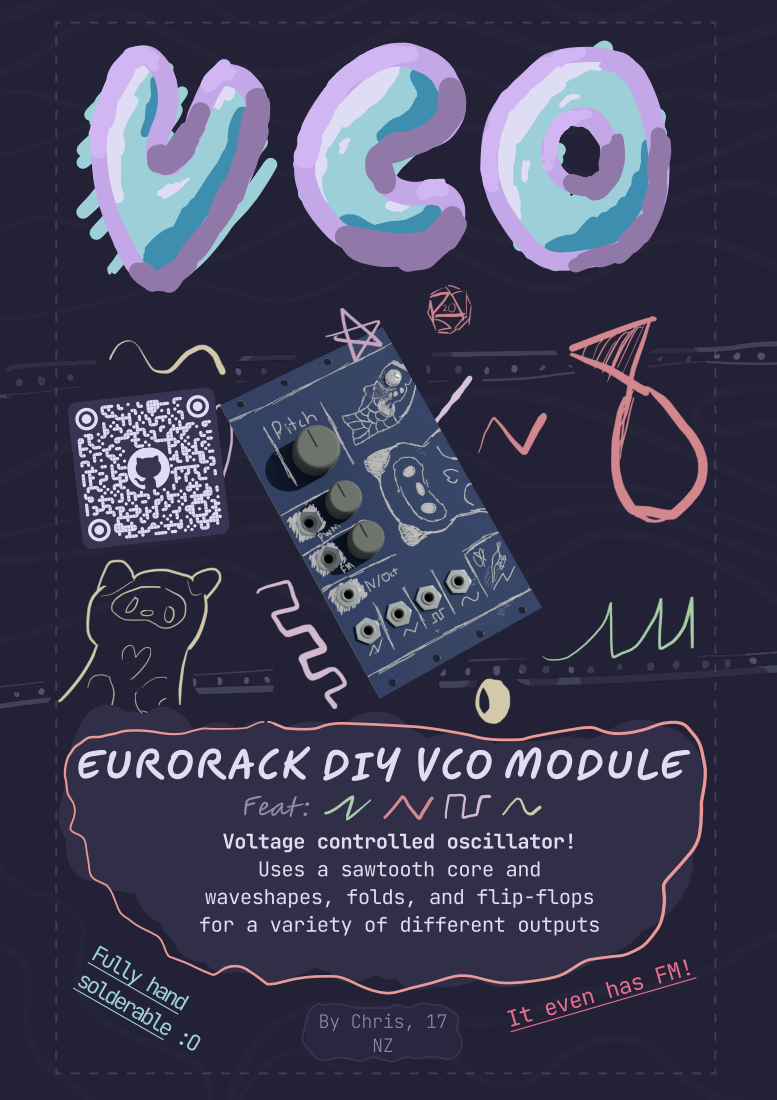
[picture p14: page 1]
Feat:; Fully hand solderable :O; By Chris, 17 NZ

EURORACK DIY VCO MODULE

Voltage controlled oscillator!
Uses a sawtooth core and

waveshapes, folds, and flip-flops
for a variety of different outputs

It even has FM!

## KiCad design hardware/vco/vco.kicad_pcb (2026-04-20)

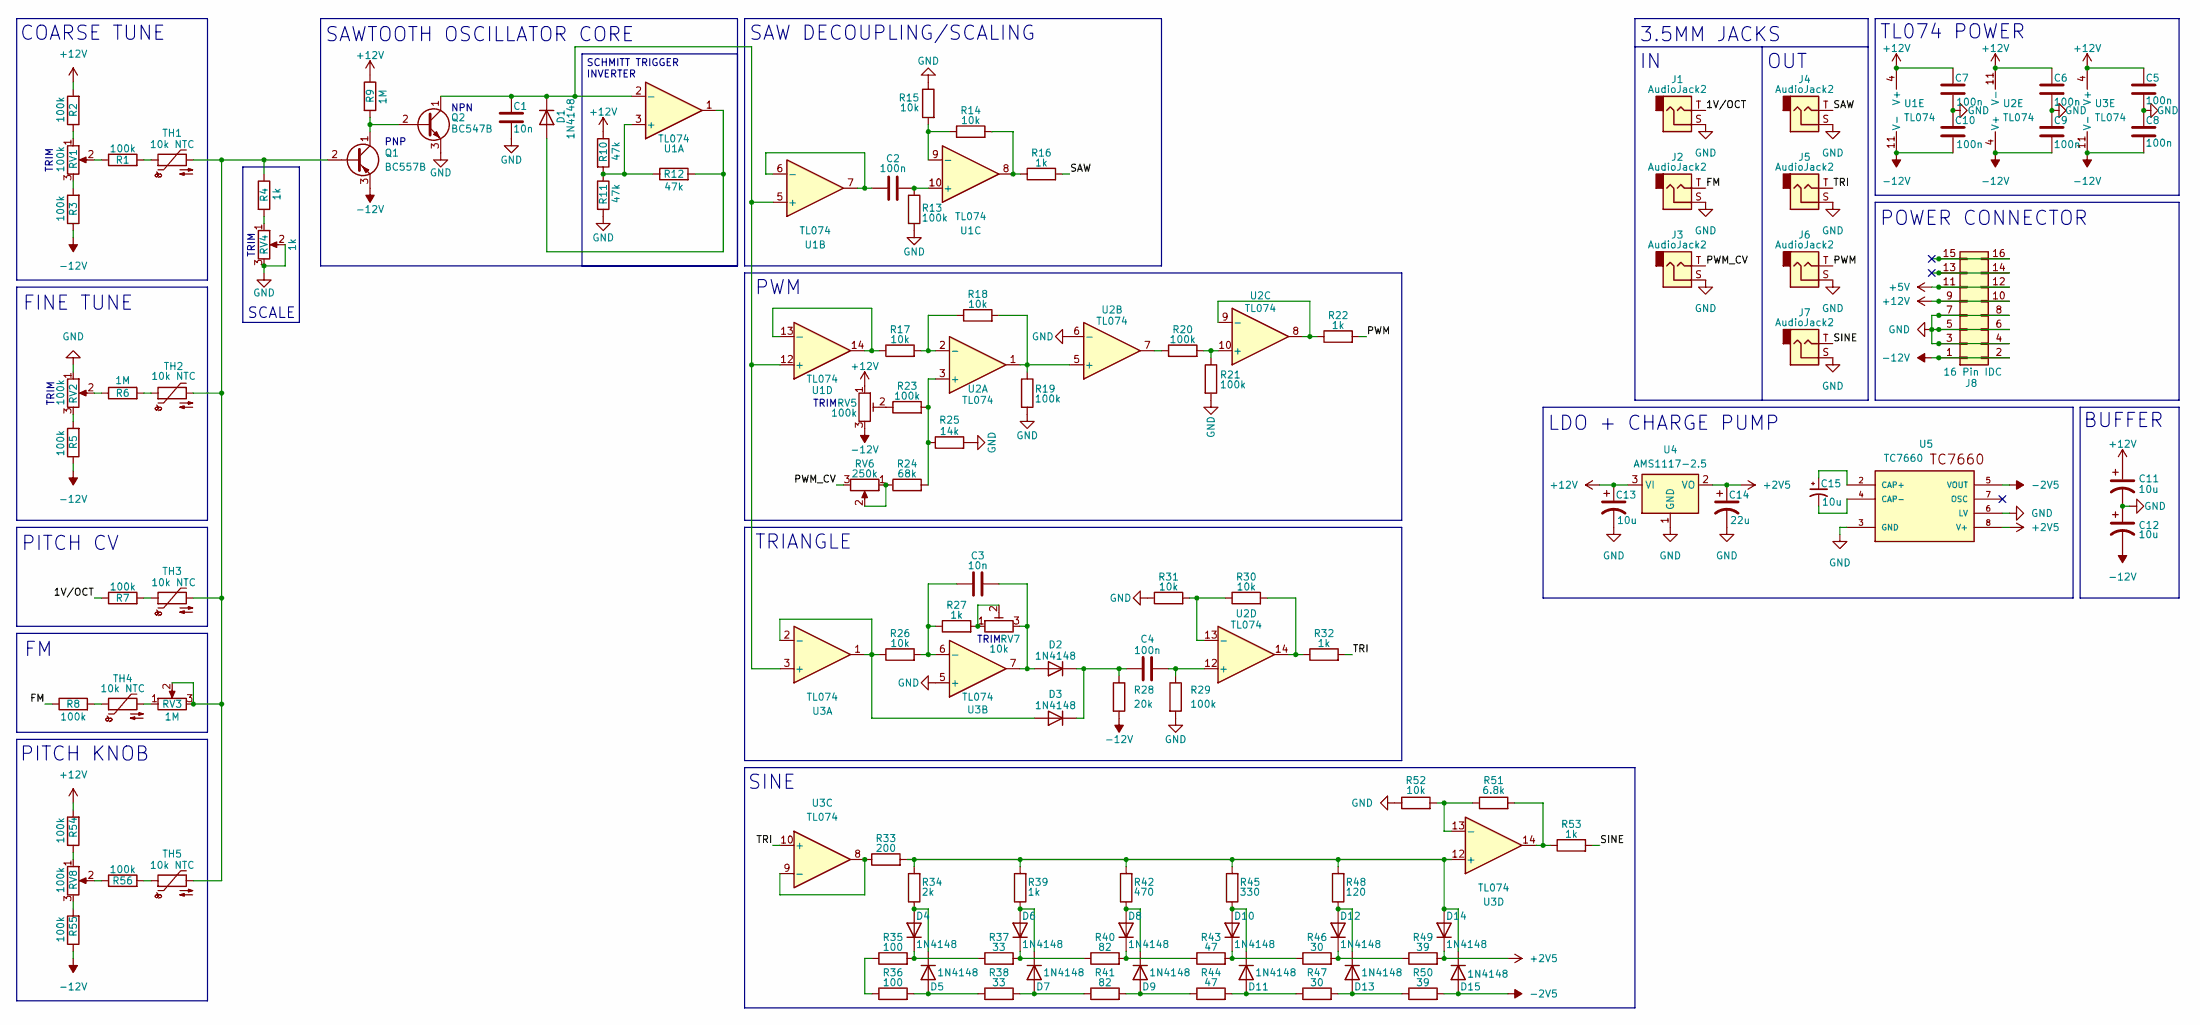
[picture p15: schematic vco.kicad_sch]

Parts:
C1, C3: 10n; C_Rect_L9.0mm_W3.3mm_P7.50mm_MKT
C2, C4, C5, C6, C7, C8, C9, C10: 100n; C_Rect_L9.0mm_W4.2mm_P7.50mm_MKT
C11, C12, C13, C15: 10u; CP_Radial_D4.0mm_P2.00mm
C14: 22u; CP_Radial_D4.0mm_P2.00mm
D1, D2, D3, D4, D5, D6, D7, D8, D9, D10, D11, D12, D13, D14, D15: 1N4148; D_DO-35_SOD27_P7.62mm_Horizontal
J1, J2, J3, J4, J5, J6, J7: AudioJack2; Jack_3.5mm_QingPu_WQP-PJ301M-12_Vertical
J8: 16 Pin IDC; IDC-Header_2x08_P2.54mm_Vertical
Q1: BC557B; TO-92_Inline
Q2: BC547B; TO-92_Inline
R1, R2, R3, R5, R7, R8, R13, R19, R20, R21, R23, R29, R54, R55, R56: 100k; R_Axial_DIN0207_L6.3mm_D2.5mm_P2.54mm_Vertical
R4, R16, R22, R27, R32, R39, R53: 1k; R_Axial_DIN0207_L6.3mm_D2.5mm_P2.54mm_Vertical
R6, R9: 1M; R_Axial_DIN0207_L6.3mm_D2.5mm_P2.54mm_Vertical
R10, R11, R12: 47k; R_Axial_DIN0207_L6.3mm_D2.5mm_P2.54mm_Vertical
R14, R15, R17, R18, R26, R30, R31, R52: 10k; R_Axial_DIN0207_L6.3mm_D2.5mm_P2.54mm_Vertical
R24: 68k; R_Axial_DIN0207_L6.3mm_D2.5mm_P2.54mm_Vertical
R25: 14k; R_Axial_DIN0207_L6.3mm_D2.5mm_P2.54mm_Vertical
R28: 20k; R_Axial_DIN0207_L6.3mm_D2.5mm_P2.54mm_Vertical
R33: 200; R_Axial_DIN0207_L6.3mm_D2.5mm_P2.54mm_Vertical
R34: 2k; R_Axial_DIN0207_L6.3mm_D2.5mm_P2.54mm_Vertical
R35, R36: 100; R_Axial_DIN0207_L6.3mm_D2.5mm_P2.54mm_Vertical
R37, R38: 33; R_Axial_DIN0207_L6.3mm_D2.5mm_P2.54mm_Vertical
R40, R41: 82; R_Axial_DIN0207_L6.3mm_D2.5mm_P2.54mm_Vertical
R42: 470; R_Axial_DIN0207_L6.3mm_D2.5mm_P2.54mm_Vertical
R43, R44: 47; R_Axial_DIN0207_L6.3mm_D2.5mm_P2.54mm_Vertical
R45: 330; R_Axial_DIN0207_L6.3mm_D2.5mm_P2.54mm_Vertical
R46, R47: 30; R_Axial_DIN0207_L6.3mm_D2.5mm_P2.54mm_Vertical
R48: 120; R_Axial_DIN0207_L6.3mm_D2.5mm_P2.54mm_Vertical
R49, R50: 39; R_Axial_DIN0207_L6.3mm_D2.5mm_P2.54mm_Vertical
R51: 6.8k; R_Axial_DIN0207_L6.3mm_D2.5mm_P2.54mm_Vertical
RV1, RV2, RV5: 100k; TRIM_3362P-1-253LF
RV3: 1M; Potentiometer_Alps_RK09L_Single_Vertical
RV4: 1k; TRIM_3362P-1-253LF
RV6: 250k; Potentiometer_Alps_RK09L_Single_Vertical
RV7: 10k; TRIM_3362P-1-253LF
RV8: 100k; Potentiometer_Alps_RK09L_Single_Vertical
TH1, TH2, TH3, TH4, TH5: 10k NTC; R_Axial_DIN0204_L3.6mm_D1.6mm_P1.90mm_Vertical
U1, U2, U3: TL074; DIP-14_W7.62mm
U4: AMS1117-2.5; SOT-223-3_TabPin2
U5: TC7660; DIL08

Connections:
+2V5: C14.1, D14.1 (K), R49.2, U4.2 (VO), U5.8 (V+)
+5V: J8.11, J8.12
+12V: C5.1, C6.1, C7.1, C11.1, C13.1, J8.9, J8.10, R2.2, R9.1, R10.1, R54.2, RV5.1, U1.4 (V+), U2.11 (V-), U3.4 (V+), U4.3 (VI)
-2V5: D15.2 (A), R50.2, U5.5 (VOUT)
-12V: C8.2, C9.2, C10.2, C12.2, J8.1, J8.2, Q1.3 (E), R3.1, R5.1, R28.2, R55.1, RV5.3, U1.11 (V-), U2.4 (V+), U3.11 (V-)
/1V/OCT: J1.T, R7.1
/FM: J2.T, R8.1
/PWM: J6.T, R22.2
/PWM_CV: J3.T, RV6.3
/SAW: J4.T, R16.2
/SINE: J7.T, R53.2
/TRI: J5.T, R32.2, U3.10 (+)
GND: C1.2, C5.2, C6.2, C7.2, C8.1, C9.1, C10.1, C11.2, C12.1, C13.2, C14.2, J1.S, J2.S, J3.S, J4.S, J5.S, J6.S, J7.S, J8.3, J8.4, J8.5, J8.6, J8.7, J8.8, Q2.3 (E), R11.2, R13.2, R15.1, R19.2, R21.2, R25.2, R29.2, R31.1, R52.1, RV2.1, RV4.2, RV4.3, U2.6 (-), U3.5 (+), U4.1 (GND), U5.3 (GND), U5.6 (LV)
unnamed: D1.2 (A), R12.2, U1.1
unnamed: C1.1, D1.1 (K), Q2.1 (C), U1.2 (-), U1.5 (+), U1.12 (+), U3.3 (+)
unnamed: C3.2, D2.2 (A), RV7.3, U3.7
unnamed: C4.1, D2.1 (K), D3.1 (K), R28.1
unnamed: D3.2 (A), R26.1, U3.1, U3.2 (-)
unnamed: D4.2 (A), D5.1 (K), R34.1
unnamed: D4.1 (K), R35.2, R37.1
unnamed: D5.2 (A), R36.2, R38.1
unnamed: D6.2 (A), D7.1 (K), R39.1
unnamed: D6.1 (K), R37.2, R40.1
unnamed: D7.2 (A), R38.2, R41.1
unnamed: D8.2 (A), D9.1 (K), R42.1
unnamed: D8.1 (K), R40.2, R43.1
unnamed: D9.2 (A), R41.2, R44.1
unnamed: D10.2 (A), D11.1 (K), R45.1
unnamed: D10.1 (K), R43.2, R46.1
unnamed: D11.2 (A), R44.2, R47.1
unnamed: D12.2 (A), D13.1 (K), R48.1
unnamed: D12.1 (K), R46.2, R49.1
unnamed: D13.2 (A), R47.2, R50.1
unnamed: D14.2 (A), D15.1 (K), R33.2, R34.2, R39.2, R42.2, R45.2, R48.2, U3.12 (+)
unnamed: Q1.2 (B), R4.1, RV3.2, RV3.3, TH1.2, TH2.2, TH3.2, TH5.2
unnamed: Q1.1 (C), Q2.2 (B), R9.2
unnamed: R1.1, RV1.2
unnamed: R1.2, TH1.1
unnamed: R2.1, RV1.1
unnamed: R3.2, RV1.3
unnamed: R4.2, RV4.1
unnamed: R5.2, RV2.3
unnamed: R6.1, RV2.2
unnamed: R6.2, TH2.1
unnamed: R7.2, TH3.1
unnamed: R8.2, TH4.1
unnamed: R14.2, R16.1, U1.8
unnamed: R20.1, U2.7
unnamed: R23.1, RV5.2
unnamed: R24.1, RV6.1, RV6.2
unnamed: R27.2, RV7.1, RV7.2
unnamed: R30.2, R32.1, U2.14
unnamed: R35.1, R36.1
unnamed: R51.2, R53.1, U3.14
unnamed: R54.1, RV8.1
unnamed: R55.2, RV8.3
unnamed: R56.1, RV8.2
unnamed: R56.2, TH5.1
unnamed: RV3.1, TH4.2
unnamed: R10.2, R11.1, R12.1, U1.3 (+)
unnamed: C2.1, U1.6 (-), U1.7
unnamed: C2.2, R13.1, U1.10 (+)
unnamed: R14.1, R15.2, U1.9 (-)
unnamed: R17.1, U1.13 (-), U1.14
unnamed: R23.2, R24.2, R25.1, U2.3 (+)
unnamed: R17.2, R18.1, U2.2 (-)
unnamed: R18.2, R19.1, U2.1, U2.5 (+)
unnamed: R20.2, R21.1, U2.10 (+)
unnamed: R22.1, U2.8, U2.9 (-)
unnamed: C4.2, R29.1, U2.12 (+)
unnamed: R30.1, R31.2, U2.13 (-)
unnamed: C3.1, R26.2, R27.1, U3.6 (-)
unnamed: R33.1, U3.8, U3.9 (-)
unnamed: R51.1, R52.2, U3.13 (-)
unnamed: C15.1, U5.2 (CAP+)
unnamed: C15.2, U5.4 (CAP-)

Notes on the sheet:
TL074 POWER
NPN
SCALE
PITCH KNOB
FINE TUNE
COARSE TUNE
SINE
PNP
BUFFER
SCHMITT TRIGGER INVERTER
LDO + CHARGE PUMP
OUT
TRIM
3.5MM JACKS
TRIANGLE
PWM
SAWTOOTH OSCILLATOR CORE
SAW DECOUPLING/SCALING
POWER CONNECTOR
PITCH CV

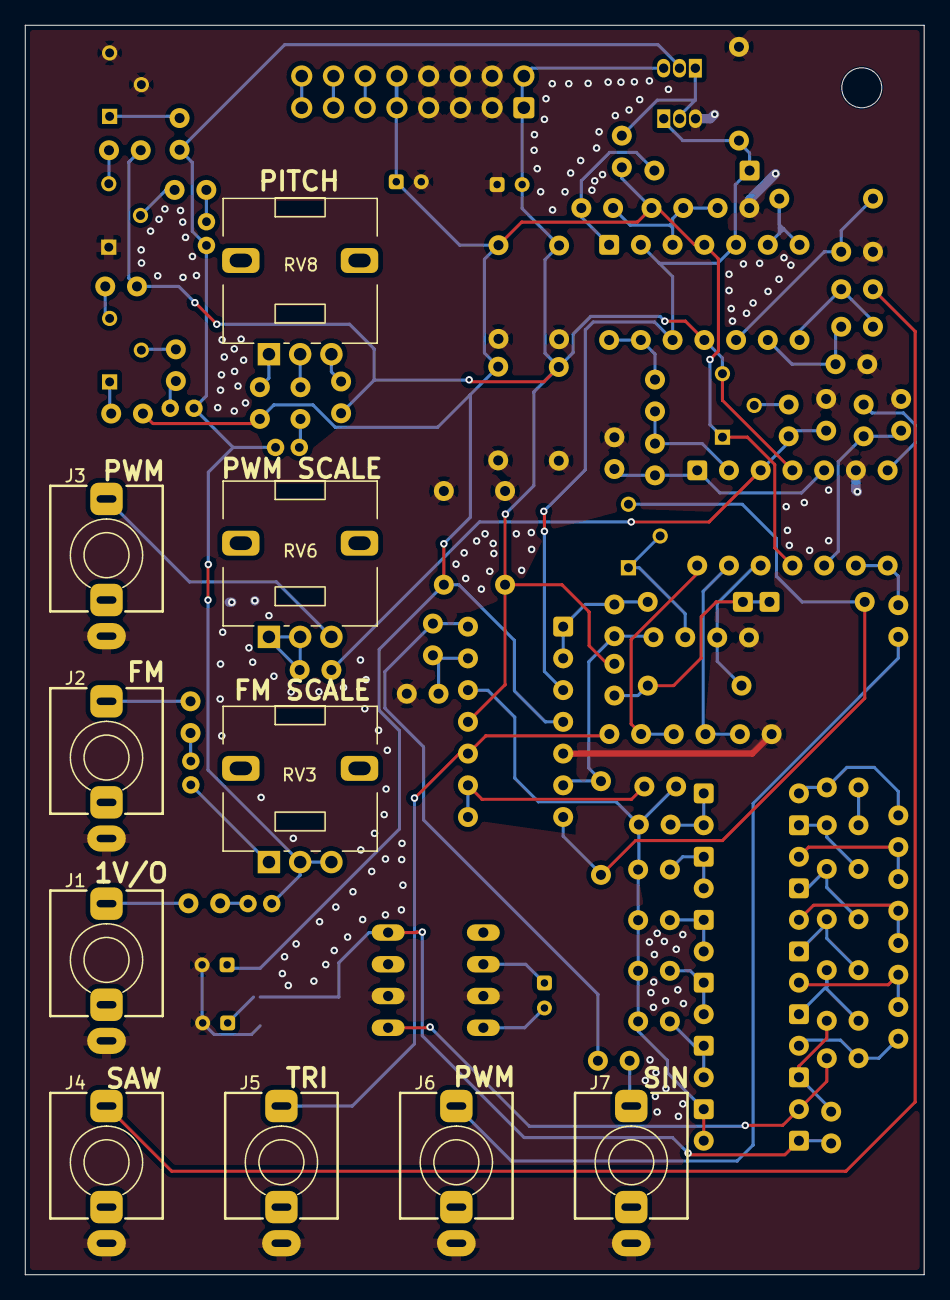
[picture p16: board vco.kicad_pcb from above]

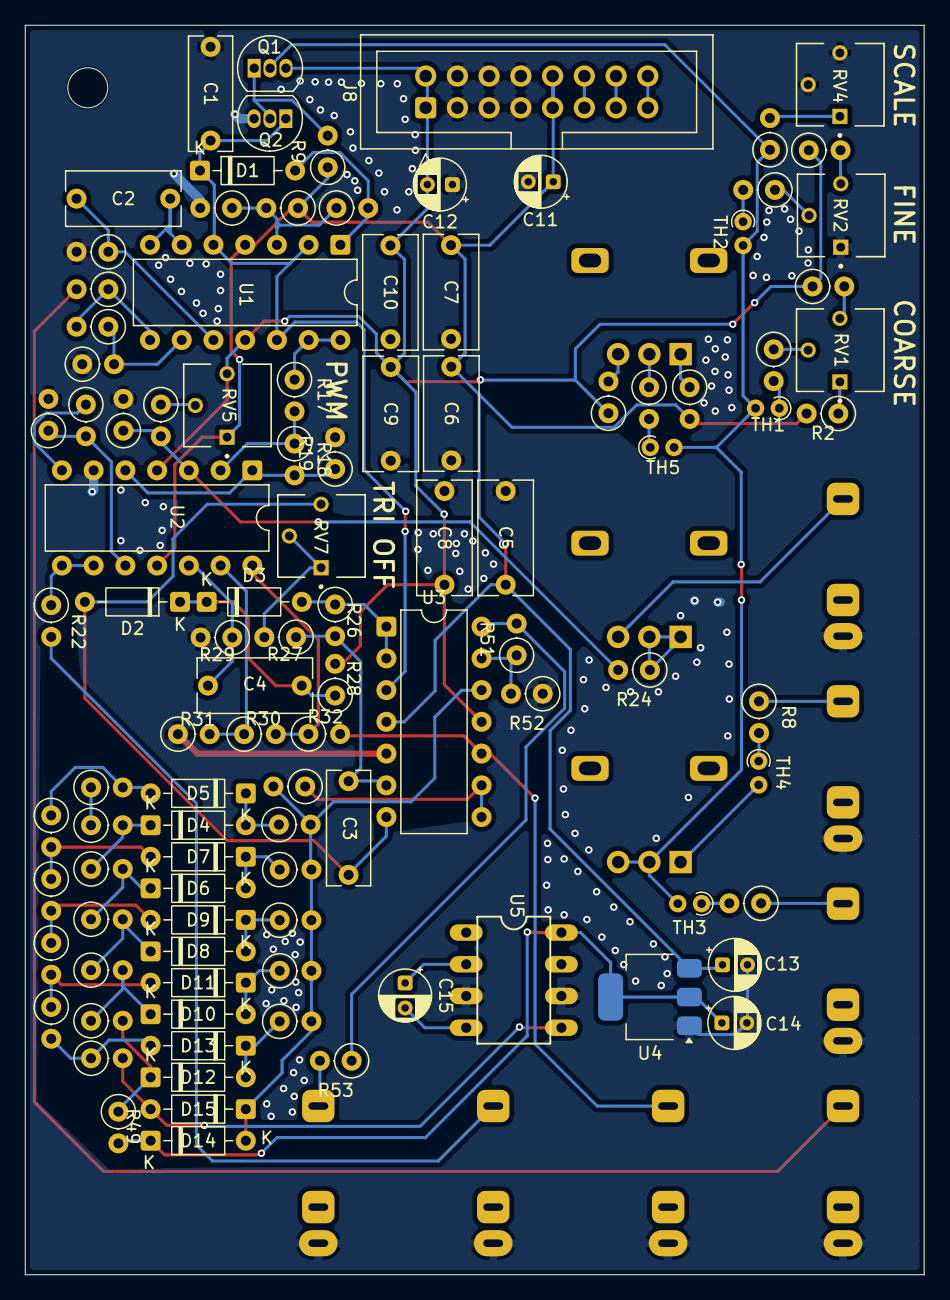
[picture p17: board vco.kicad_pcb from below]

Board: 2 copper layers, 71.9 x 100.0 mm, 114 parts (104 on the bottom side), 76 nets.

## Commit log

2026-04-18 finish circuit
2026-04-18 Start kicad schematic
    [vco.kicad_pcb, vco.kicad_sch]
2026-04-18 start of tht version
    [vco.kicad_sch]
2026-04-18 end of first layout att
    [vco.kicad_pcb, vco.kicad_sch]
2026-04-20 Polish for submission
    [BigKnob.stl, LittleKnob.stl, M7 Nut.stl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]
2026-04-25 add cad full assembly
    [assembly.step]
2026-04-28 update bom
    [bom.csv, bom.ods]
